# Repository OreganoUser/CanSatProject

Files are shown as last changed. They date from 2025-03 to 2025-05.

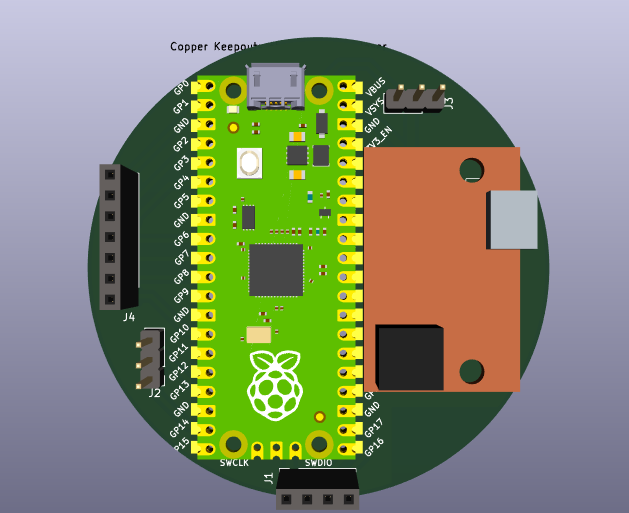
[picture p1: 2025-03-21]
PCB/model3d_1.png

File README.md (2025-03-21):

# Code Structure
## sensorsational_library
This folder contains all the functions. This folder **should be placed in the arduino libraries folder** to make it accessible to all other sketches.The functions are split up in different files depending on the component/function they belong to. The heart piece of the library is **general_definitions.h** since it contains all pin definitions, frequency definition, etc. **calibration_parameters.cpp** contains the calibration parameters for the LSM9DS1 which must be changed manually if a new calibration procedure is done.

## main
Main contains the code that is run on the can. It relies on external functions from the sensorsational_library and is kept small to keep it readable.

## calibration
calibration contains the calibration routines for the LSM9DS1 that have been taken from: https://github.com/FemmeVerbeek/Arduino_LSM9DS1/tree/master/examples. See also instructional video here: https://www.youtube.com/watch?v=BLvYFXoP33o. This calibration must be done in the real environment (inside the can with all components in place) **once** to determine the calibration parameters.

## magneto_calibration
magnet_calibration provides a better magnetic calibration than in the calibration folder. This sketch measure a large array of magnetic data and saves it as .txt file on the SD card. To get the calibration parameters, this .txt file must be loaded onto a computer and imported into the magneto v1.2 code (download here). The calibration parameters need to be input into the calibration_paramters.cpp file in the sensorsational_library.

## motor_test
motor_test is example code to set the BLDC motor speed for the propellers. To be done: implement functions that set motor speeds and can be called inside the main code and add them to the sensorsational_library.

## orientation
orientation contains example code on how to use the SensorFusion library to calculate the magnetic heading. To be done: implement functions that can be called inside the main code and add them to the sensorsational_library.

## receiver
receiver is example code for receiving the data (groundstation) from the radio module and outputting them to the serial.

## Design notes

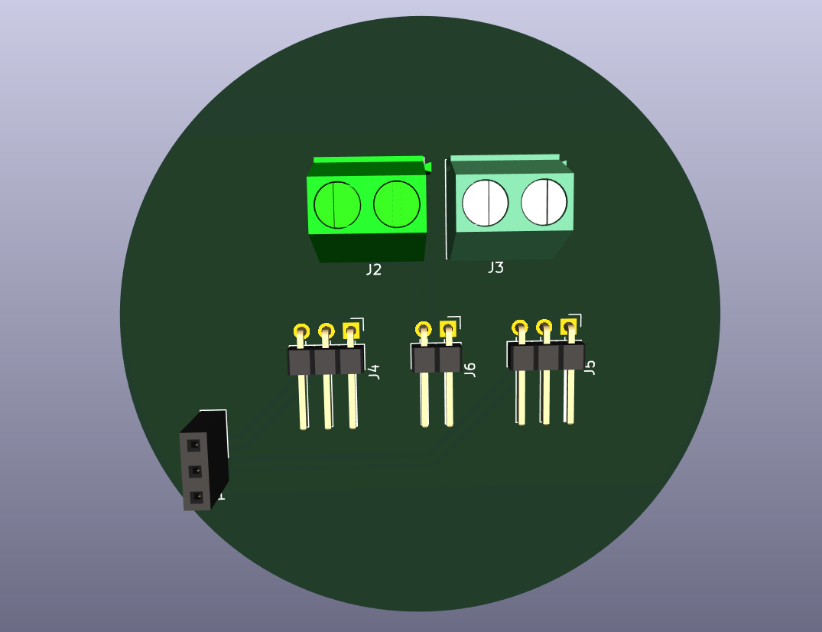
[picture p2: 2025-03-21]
PCB/model3d_0.png

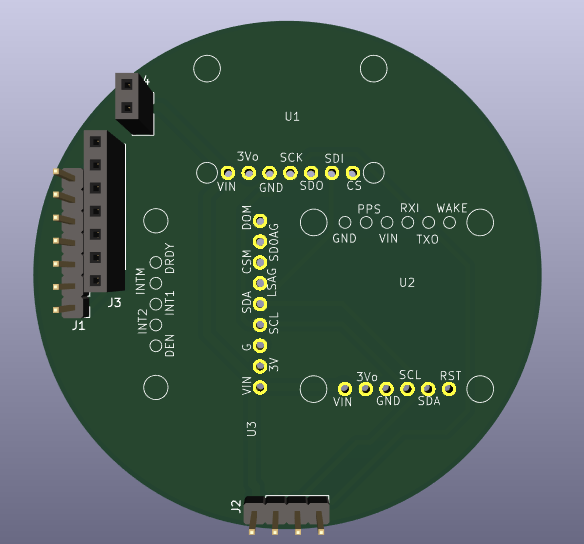
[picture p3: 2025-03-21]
PCB/model3d_2.png

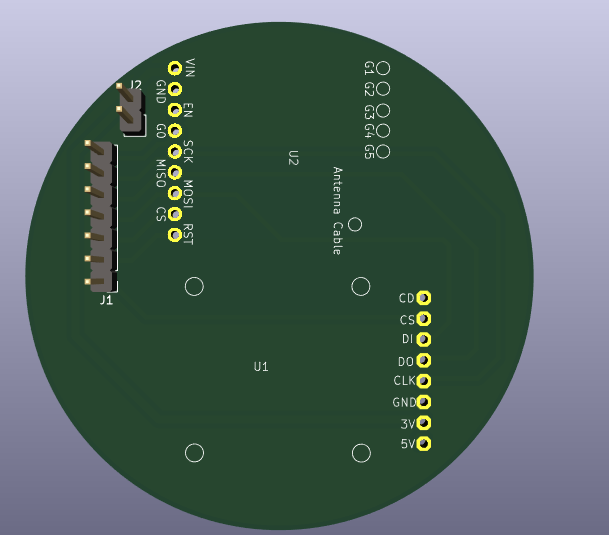
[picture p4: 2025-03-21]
PCB/model3d_3.png

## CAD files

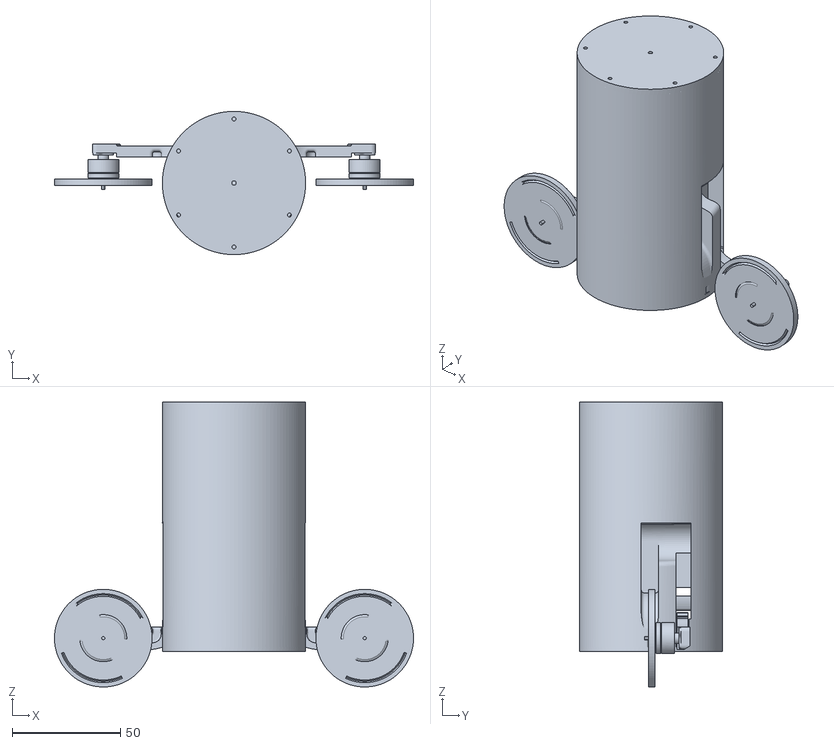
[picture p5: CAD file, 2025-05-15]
Evaluation/canSat prototyp 3 (platzoptimisation) v19.stl
165.5 x 66.0 x 131.3

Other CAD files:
Evaluation/animation.blend

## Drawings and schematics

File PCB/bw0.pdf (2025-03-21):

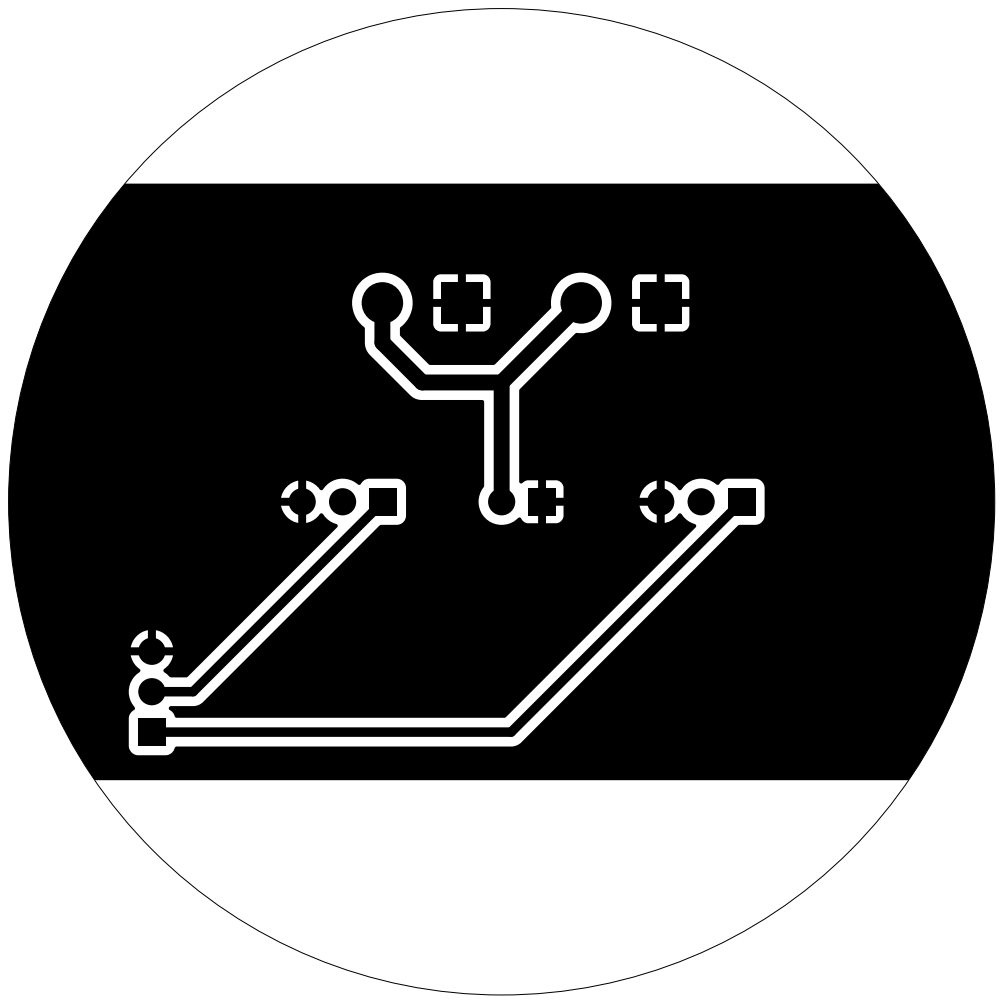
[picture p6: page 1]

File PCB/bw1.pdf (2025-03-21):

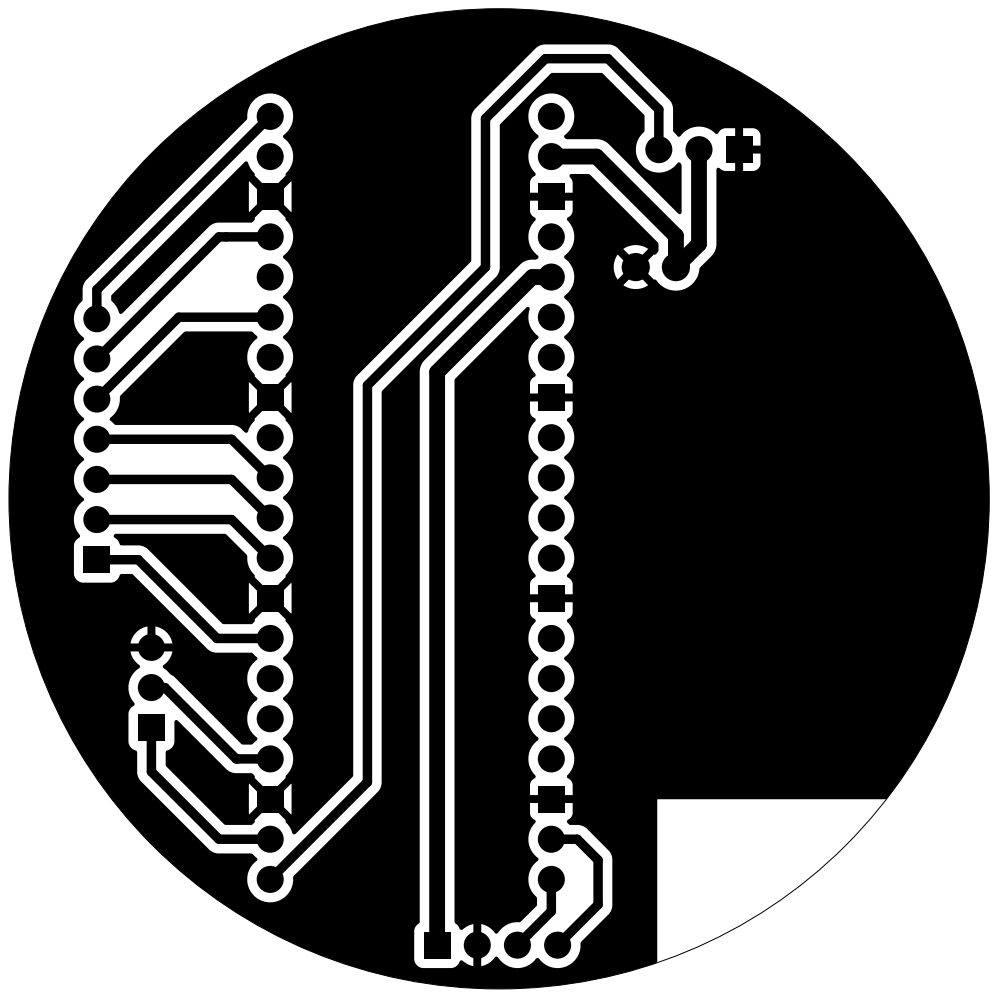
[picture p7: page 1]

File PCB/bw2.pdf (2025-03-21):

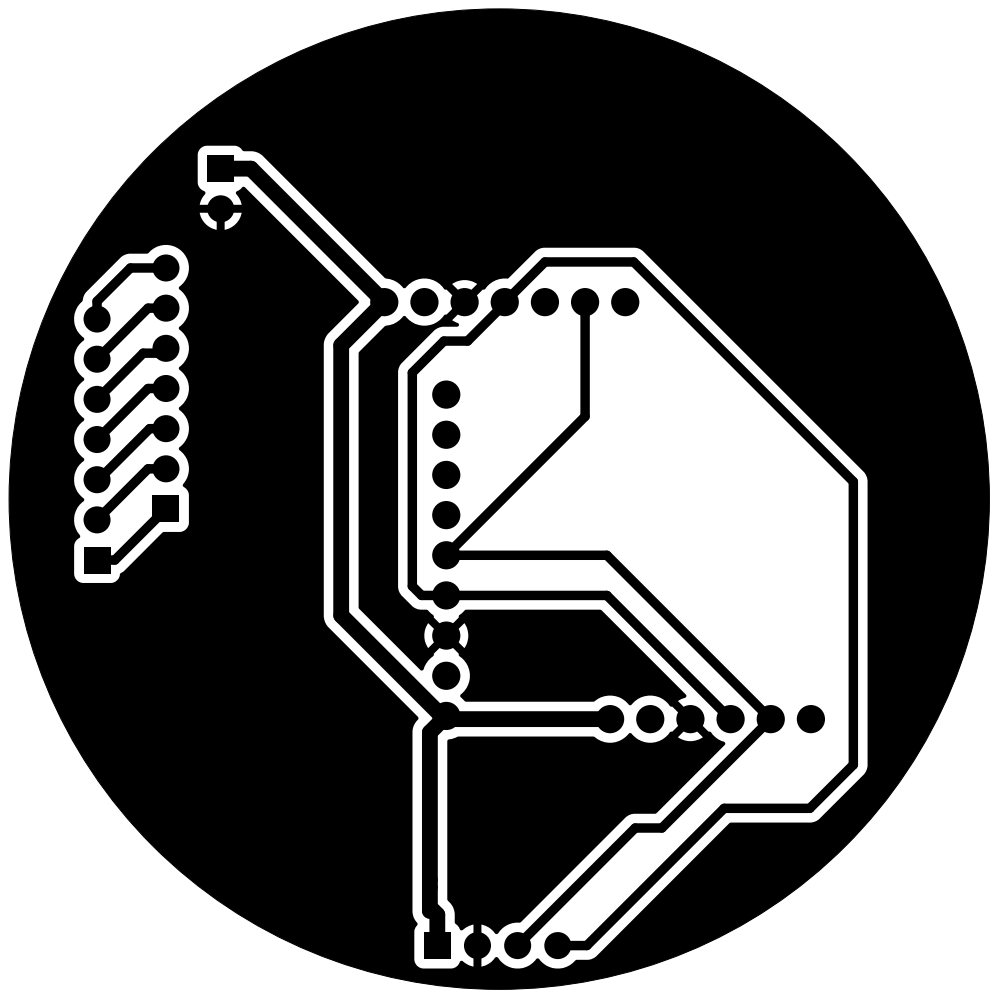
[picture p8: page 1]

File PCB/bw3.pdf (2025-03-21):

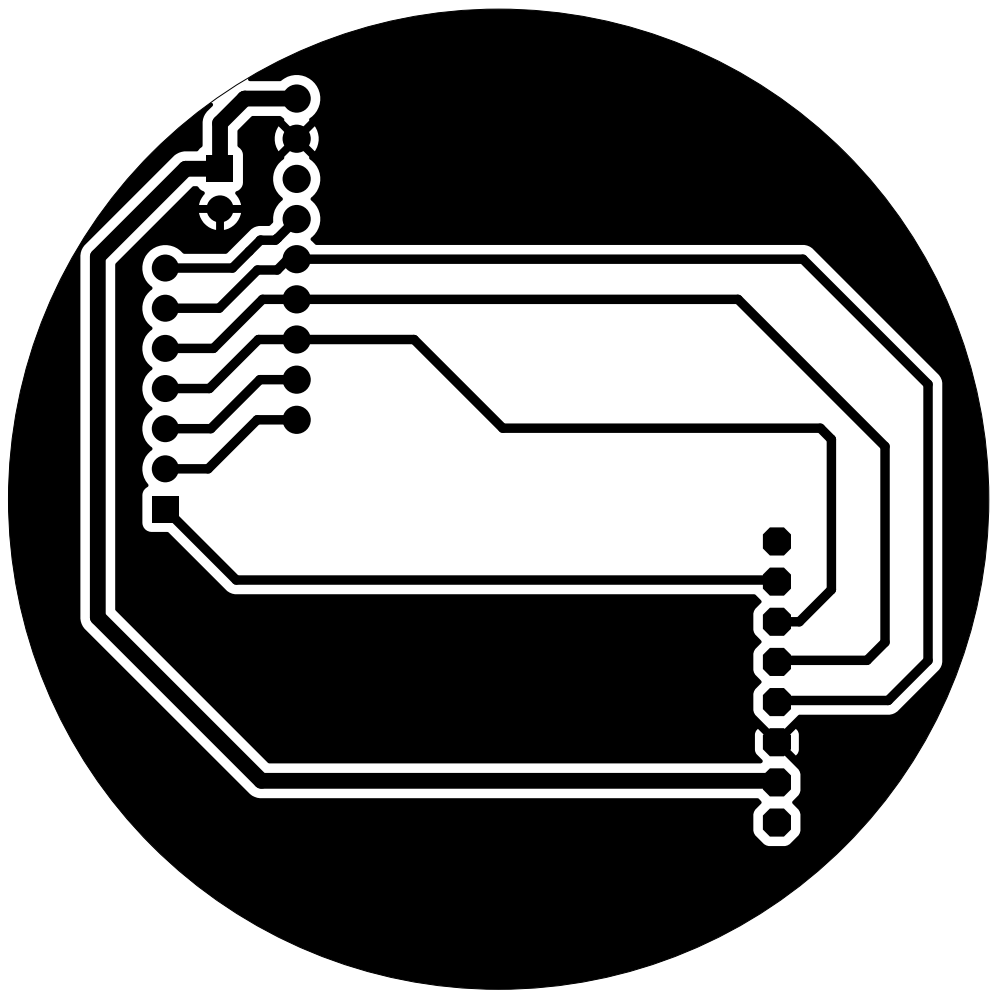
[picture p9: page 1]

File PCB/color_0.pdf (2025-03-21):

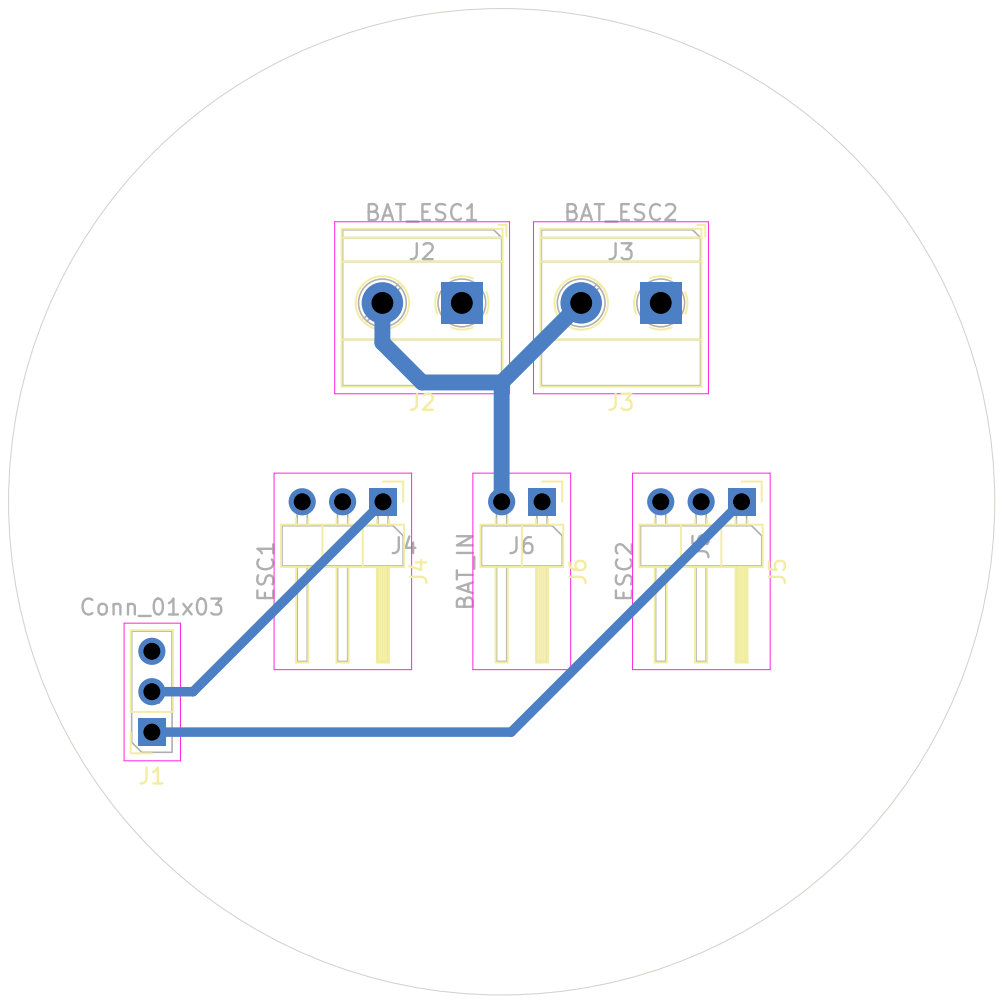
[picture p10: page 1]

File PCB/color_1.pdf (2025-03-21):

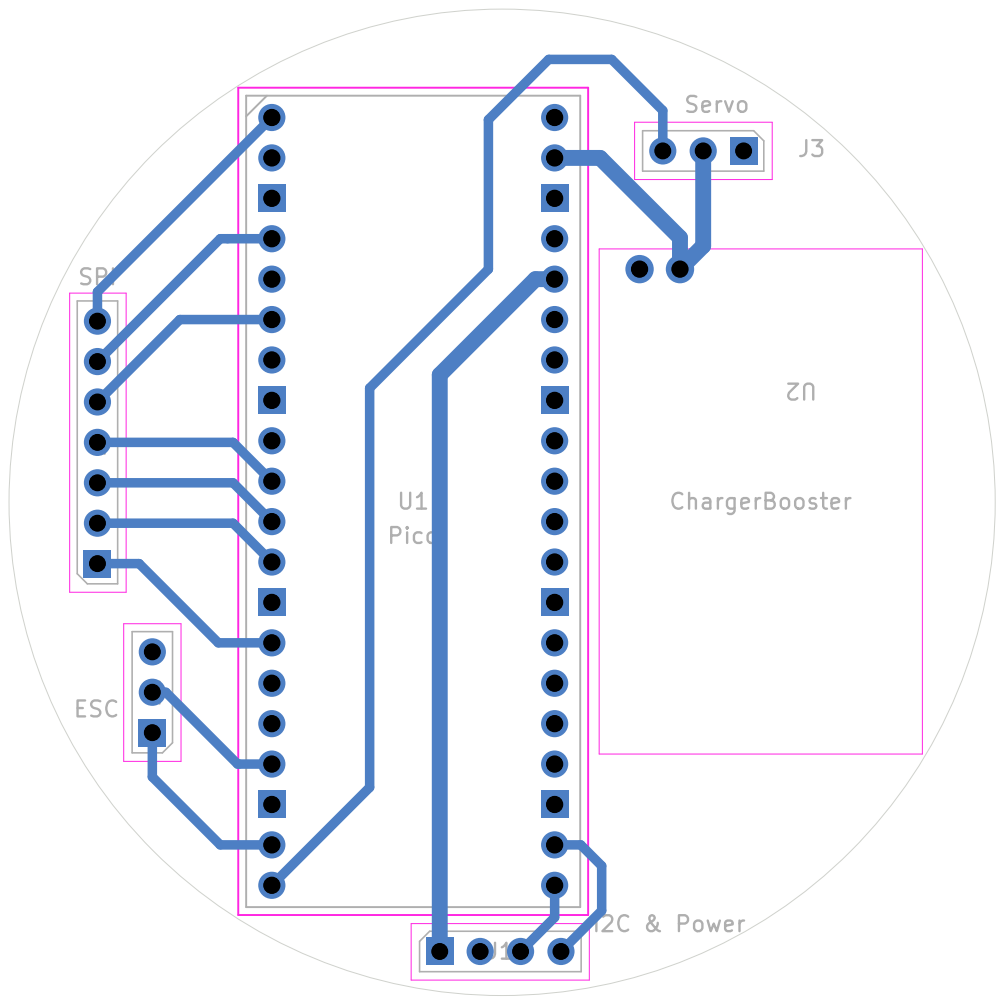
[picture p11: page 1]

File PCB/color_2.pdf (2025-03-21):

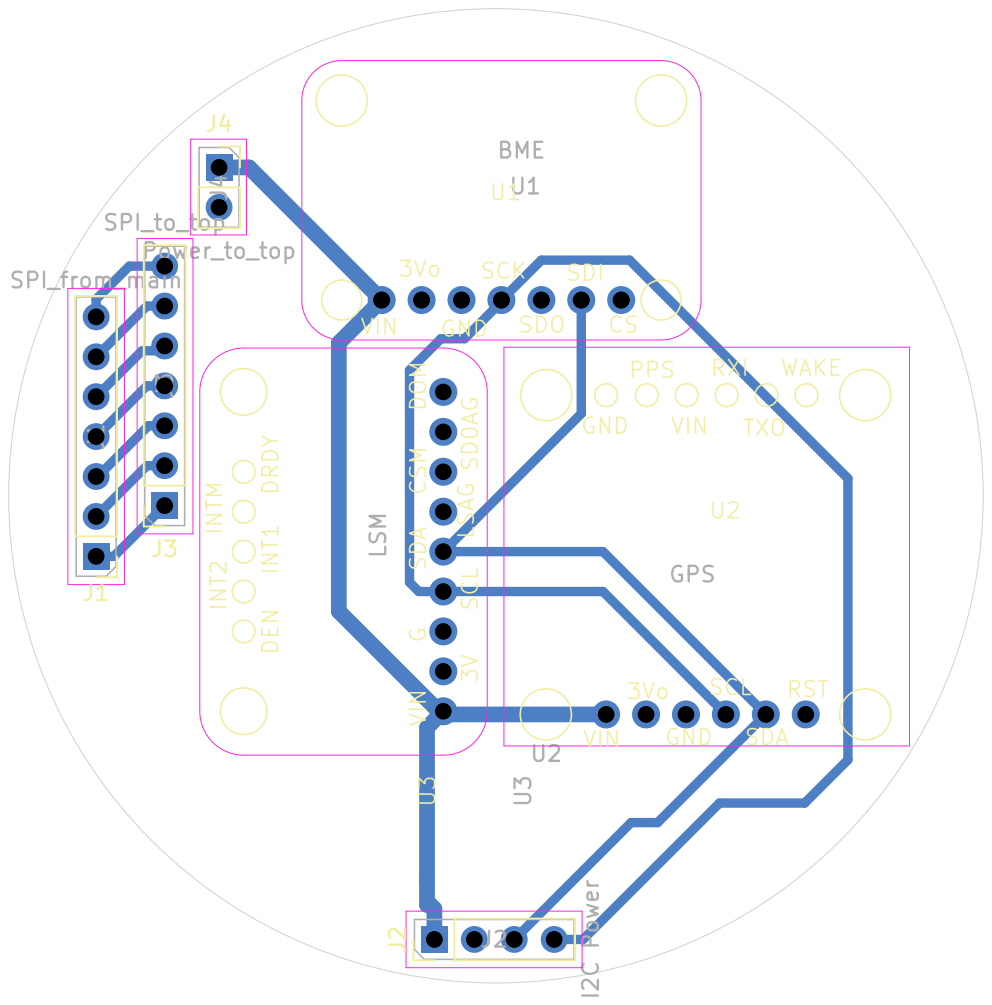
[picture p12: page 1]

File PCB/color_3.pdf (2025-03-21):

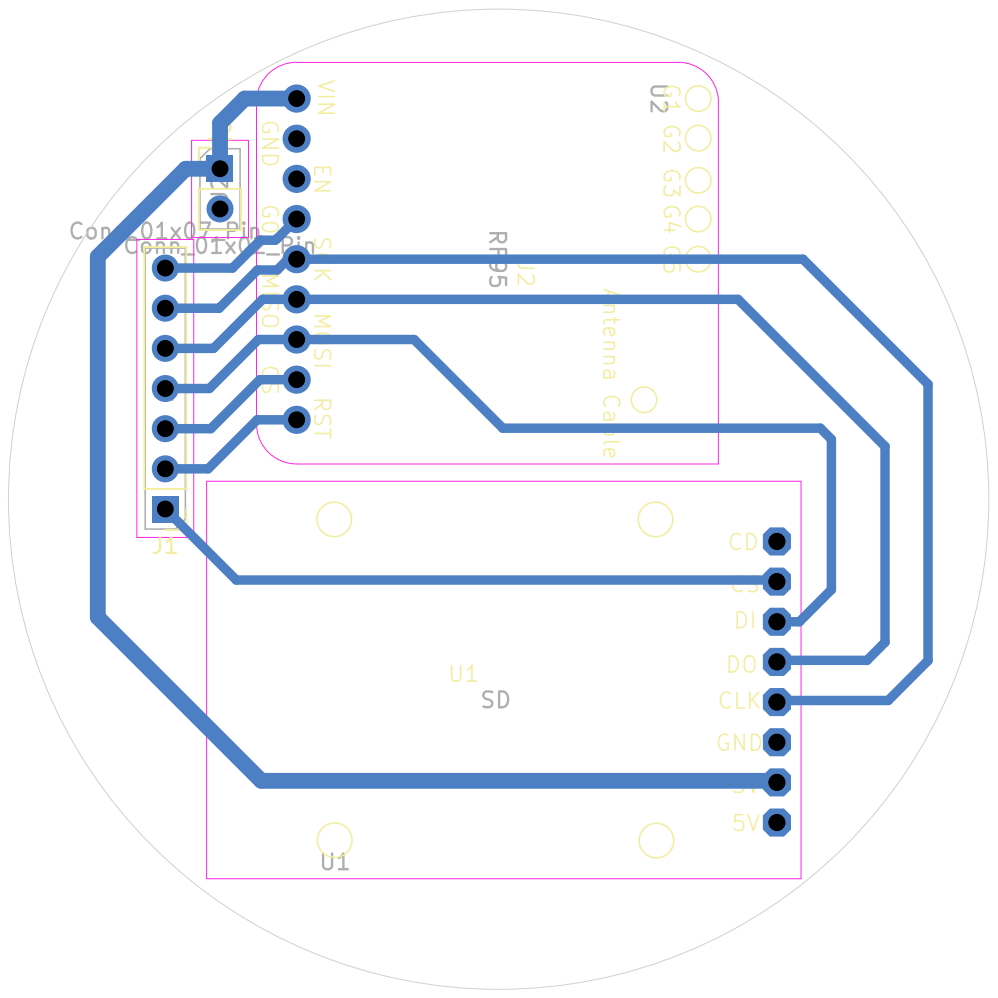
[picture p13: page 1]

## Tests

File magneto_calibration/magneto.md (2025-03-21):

The magneto program provides a better magnetic calibration than the simple model used in /calibration.

# Procedure
- Execute the the magneto_calibration.ino sketch and rotate the can around. Make sure to get all possible positions of the can!
- The data is measured during a certain duration (can be set in the sketch).
- After the measurement is done, take the created .txt file from the SD card and transfer it to the computer.
- Load the .txt file into the magneto program, set the magnetic field strength (taken from here: [Magnetic Field Strenght Calculator](https://www.ngdc.noaa.gov/geomag/calculators/magcalc.shtml#igrfwmm) ) and execute.
- Write the parameters into the calibration_parameters.cpp file (combined bias -> magBias and the 9 values are written to softIron in the following order: upper left, upper centre, upper right, second row left, ...).

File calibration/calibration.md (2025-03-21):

# Explanations for the calibration procedure
This procedure is taken from https://github.com/FemmeVerbeek/Arduino_LSM9DS1/tree/master/examples.
An instructional video that shows the procedure can be found here: https://www.youtube.com/watch?v=BLvYFXoP33o

## Setting up the code
- The sensorsational_library must be in the arduino/libraries folder.
- The SensorFusion (https://github.com/aster94/SensorFusion/tree/master/examples) library must be installed.
- Change Line 33 in the file: Arduino/libraries/Sensorfusion/src/Sensorfusion.cpp to #define betaDef     2.0f        	// 2 * proportional gain

## Executing the accelerometer calibration
- Set the can on a horizontal surface (use a water level!) and leave it. It is important that it isn't moving during calibration.
- Execute calibration.ino and select accelerometer.
- Follow the instructions and do the calibration for the 3 axes (axes are labelled on the LSM9DS1).

## Executing the gyro calibration
- Set the can on a flat horizontal surface.
- Execute calibration.ino and select gyro.
- Follow the instructions. The rotation angle can be set in the code (the bigger, the better in theory)
- Repeat for all 3 axes.

## Executing the magnetic calibration
- The magnetic field strength must be looked up (https://www.ngdc.noaa.gov/geomag/calculators/magcalc.shtml#igrfwmm) and put into the general_definitions.h file.
- **Make sure you are away from all magnetic disturbance (power outlets, speakers, ...)!** This is best done outside and in the real environment (with all components installed).
- Follow the instructions on the screen and rotate the can around all axes.
- Stop when the max and min values don't change much anymore.
- Note: the magneto_calibration is preferred because it's more accurate.

## Setting the calibration parameters
- Write the determined parameters into the calibration_parameters.cpp file.
- For the simple magnetic calibration, use magOffsets and magSlopes. If the magneto calibration is done, use magBias and softIron.

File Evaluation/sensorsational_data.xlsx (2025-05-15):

Data | Packet Number | Timestamp (s) | Temperature (°C) | Pressure (hPa) | Altitude (m) | Humidity (%) | GPS Fix | Latitude | Longitude | Altitude (m) | Speed (knots) | Angle (°) | ax (m/s2) | ay (m/s2) | az (m/s2) | gx (rad/s) | gy( rad/s) | gz (rad/s) | mx (microTesla) | my (microTesla) | mz (microTesla) | Yaw (°) | Roll (°) | Pitch (°) | Flight Stage | RSSI
Variable Type | int | Float, 1 decimal | Float, 1 decimal | Float, 1 decimal | Float, 1 decimal | int | int | Float, 5 decimals | Float, 5 decimals | Float, 1 decimal | Float, 3 decimals | int | Float, 4 decimals | Float, 4 decimals | Float, 4 decimals | Float, 4 decimals | Float, 4 decimals | Float, 4 decimals | Float, 4 decimals | Float, 4 decimals | Float, 4 decimals | int | int | int | int | int (negative value)
Explanation |  |  |  |  |  |  | Is actually of bool type. 0: GPS has no fix, 1: GPS has fix |  |  | This value can be different from the altitude that is determined from pressure sensor. | Speed over ground (horizontal speed). Needs to be converted to m/s! | This is the direction we are moving in. |  |  |  |  |  |  |  |  |  | Is basically the same as magnetic heading | Inclination of Cansat (leaning left or right) | Inclination of Cansat (looking up or down) | -1: value before things have been calculated 0: before launch 1: launch detected 2: reached a specific threshold height with rocket 3: Cansat fall detected 4: Cansat close to ground | Signal strength, the bigger the number (the less negative), the better ist the reception
What can we do with this data? |  |  | Graph as function of time | Display value on dashboard | Graph as function of time. Calculate vertical descent speed and display as function of time | Display value on dashboard | Display value on dashboard (red and green light?) | Display value on dashboard. Plot position on map. | Display value on dashboard. Plot position on map. |  | Graph as function of time. | Display value on dashboard. Could be drawn as arrow on map. |  |  |  |  |  |  |  |  |  |  |  |  | Display the flight stage on dashboard | Display the flight stage on dashboard

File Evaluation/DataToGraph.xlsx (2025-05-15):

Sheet: data
PackeNumber | Timestamp | Temperature | Pressure | Altitude (Pressure) | Humidity | GPSFix | Latitude | Longitude | Altitude (GPS) | Speed (Knots) | Angle | ax | ay | az | gx | gy | gz | mx | my | mz | Magheading | Yaw | Roll | Pitch | FlightStage
0 | 27.3 | 28.1 | 952.6 | 531.9 | 39 | 0 | 0 | 0 | 0 | 0 | 0 | 1.0324 | -0.0397 | 9.7728 | 0.0401 | 0.0395 | 0.029 | 10.3471 | 25.5243 | -34.4517 | 207 | 60 | -144 | -59 | 0
1 | 27.5 | 24.2 | 946.8 | 582.6 | 40 | 0 | 0 | 0 | 0 | 0 | 0 | 2.315 | -0.4971 | 9.4018 | 0.0237 | 0.0193 | -0.1156 | 9.3375 | 26.7741 | -35.3652 | 207 | 60 | -143 | -60 | 0
2 | 27.9 | 23.6 | 945.9 | 590.8 | 38 | 0 | 0 | 0 | 0 | 0 | 0 | 0.8691 | 0.0124 | 9.8925 | 0.0704 | 0.0819 | 0.0554 | 10.1578 | 27.1099 | -35.8639 | 208 | 62 | -144 | -59 | 1
3 | 28.3 | 23.9 | 946.3 | 587.3 | 39 | 0 | 0 | 0 | 0 | 0 | 0 | 1.9175 | -0.3217 | 9.6601 | 0.2768 | 0.447 | 0.0128 | 15.0503 | 25.9741 | -35.828 | 199 | 58 | -141 | -56 | 1
4 | 28.8 | 23.9 | 946.4 | 586.0 | 39 | 0 | 0 | 0 | 0 | 0 | 0 | 3.6876 | -1.3088 | 8.9558 | 0.3225 | 0.733 | -0.6253 | 20.9634 | 29.2886 | -31.226 | 236 | 85 | -161 | -52 | 1
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

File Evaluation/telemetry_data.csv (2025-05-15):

PacketNumber | Timestamp | Temperature | Pressure | AltitudePressure | Humidity | GPSFix | Latitude | Longitude | AltitudeGPS | SpeedKnots | Angle | ax | ay | az | gx | gy | gz | mx | my | mz | Magheading | yaw | roll | pitch | flightStage | RSSI
746 | 355.1 | 28.6 | 949.1 | 562.9 | 40 | 1 | 50.48238 | 6.18066 | 519.7 | 0.150 | 128 | 1.1081 | -0.1902 | -9.0444 | 0.3261 | 0.0219 | 0.0135 | -20.7581 | 16.0941 | 48.6924 | 226 | 52 | -165 | -0 | 1 | -78
747 | 355.6 | 28.8 | 949.4 | 560.2 | 40 | 1 | 50.48239 | 6.18066 | 519.7 | 0.050 | 128 | 1.2821 | 0.2139 | -7.6441 | 0.0204 | 0.0784 | 0.0216 | -18.7387 | 13.5363 | 48.5726 | 229 | 54 | -164 | -3 | 1 | -76
748 | 356.0 | 28.8 | 949.3 | 561.0 | 40 | 1 | 50.48239 | 6.18066 | 519.7 | 0.050 | 128 | 1.5992 | 0.4710 | -9.4588 | -0.1141 | 0.1788 | 0.1467 | -20.2800 | 16.0953 | 47.7807 | 224 | 53 | -168 | -0 | 1 | -77
749 | 356.5 | 29.0 | 949.6 | 558.5 | 41 | 1 | 50.48238 | 6.18066 | 519.7 | 0.050 | 128 | 0.5721 | -0.9474 | -9.1148 | 0.6243 | -0.3661 | 0.3955 | -20.8277 | 20.2464 | 47.3683 | 227 | 51 | -169 | 1 | 1 | -83
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

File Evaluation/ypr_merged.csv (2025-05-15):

time_s | yaw_deg | pitch_deg | roll_deg
2502 | 276 | -20 | -3
2502 | 275 | -15 | 0
2503 | 280 | -12 | -2
2503 | 275 | -10 | -2
2504 | 272 | -9 | -4
2504 | 267 | -9 | 2
2505 | 263 | -10 | -1
2505 | 255 | -11 | 3
2505 | 252 | -11 | 4
2506 | 247 | -12 | 6
2506 | 241 | -12 | 8
2507 | 236 | -13 | 8
2507 | 227 | -13 | 12
2508 | 221 | -15 | 15
2508 | 215 | -13 | 15
2509 | 208 | -15 | 17
2509 | 201 | -12 | 23
2510 | 194 | -10 | 24
2510 | 189 | -9 | 29
2510 | 182 | -8 | 36
2511 | 176 | -7 | 39
2511 | 171 | -5 | 43
2512 | 165 | 1 | 48
2512 | 160 | 6 | 50
2513 | 155 | 16 | 52
2513 | 151 | 23 | 56
2514 | 149 | 29 | 58
2514 | 147 | 38 | 60
2515 | 147 | 47 | 63
2515 | 145 | 57 | 62
2515 | 148 | 66 | 64
2516 | 151 | 75 | 68
2516 | 167 | 81 | 83
2517 | 234 | 85 | 149
2517 | 48 | 47 | -61
2518 | 255 | 29 | -61
2518 | 220 | 7 | 56
2519 | 71 | -51 | 60
2519 | 32 | 51 | -44
2520 | 277 | 40 | 7
2520 | 317 | -44 | -153
2521 | 171 | 11 | 29
2521 | 135 | -29 | -96
2521 | 270 | -26 | 157
2522 | 16 | 45 | -159
2522 | 114 | 13 | 144
2523 | 240 | 32 | -107
2523 | 298 | -24 | 151
2524 | 53 | 62 | -146
2524 | 160 | 13 | 176
2525 | 274 | 15 | 142
2525 | 90 | 53 | -125
2526 | 193 | 3 | -179
2526 | 277 | 58 | 103
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

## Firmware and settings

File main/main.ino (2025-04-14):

#include "general_definitions.h"
#include "bme_functions.h"
#include "gps_functions.h"
#include "lsm9ds1_functions.h"
#include "sd_functions.h"
#include "rf69_functions.h"
#include "rf95_functions.h"
#include "orientation.h"
#include "direction_control.h"
#include "flight_stages.h"



// define array for saving timestamp
float time_array[1] = {0.0};
int time_precisions[1] = {1};

// Create one structure that contains all variable arrays
// Arrays for sensor variables are already defined in the respective function files
int number_of_arrays = 6;
float* data_arrays[] = {time_array, bme_data, gps_data, calibrated_lsm_data, orientation_data, flight_stage_data};
size_t data_array_sizes[] = {1, 4, 6, 9, 4, 1};
// This array holds the digits precision needed for each of the sensor variables
int* precisions[] = {time_precisions, bme_precisions, gps_precisions, lsm_precisions, orientation_precisions, flight_stage_precisions};

// Create buffer for data string
char data_string[MESSAGE_BUFFER_SIZE] = {0};

// counts how many times loop is executed
int iteration_counter = 0;


void setup() {
  // Set I2C pins
  Wire.setSDA(I2C_SDA);
  Wire.setSCL(I2C_SCL);
  Wire.setClock(400000);
  Wire.begin();

  // Set SPI PINS
  SPI.setRX(SPI_RX);
  SPI.setTX(SPI_TX);
  SPI.setSCK(SPI_SCK);

  // Start Serial and wait until it opens
  Serial.begin(115200);
  while (!Serial)
    delay(200);

  setup_bme(bme);
  setup_gps(gps);
  setup_lsm9ds1(lsm);
  setup_sd_card();
  
  // For the RF95 module to work:
  // Need to call setup_sd_card() even if no SD card is connected!
  // Else: SPI has problems and it won't work
  setup_rf95(rf95);

  initMotors(); //esc's
    escLeft.writeMicroseconds(0);
    escRight.writeMicroseconds(0);
    arms_deployed = false;

  //Servo
  //servo.attach(SERVO_PIN);
  delay(1000);
  // start time measurement (in seconds)
  time_array[0] = millis() / 1000.0;
}


void loop() {
  // Estimate heading using LSM9DS1
  // This should be done as a first step because direction control needs accurate values
  // and we need to send it back to ground station, so it needs to happen before sending!
  // the number in update_mag_heading should be about 100 (200 should also work)
  // less than that gives bad accuracy
  // much more (for example 1000) slows execution down by quite a bit
  update_mag_heading(100);
  // Execute sensor data collection and writing functions
  get_bme_data(bme_data);
  get_gps_data(gps_data);
  get_calibrated_lsm9ds1_data(lsm, calibrated_lsm_data, bias_corrected_magnetic);
  //update timestamp (in s)
  time_array[0] = millis() / 1000.0;
  create_data_string(data_string, iteration_counter, data_arrays, data_array_sizes, number_of_arrays, precisions);
  // need to do create_data_string before write_data_to_file!!!
  write_data_to_file(logfile_name, data_string);
  send_data_rf95(rf95, data_string);
  iteration_counter++;

  // automatic
  calc_flight_stage();
  //manual
  //manual_flight_stage_override();
  
  // calculate flight stage here and do actions (deploy arms, adjust direction etc) (not working well now)

  Serial.println(orientation_data[0]);
  adjustDirection();
}

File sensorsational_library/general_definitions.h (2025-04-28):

//I2C pins (BME280, GPS, LSM9DS1)
//Attention to I2C Bus! If using I2C0 bus, we need to use Wire
//if using I2C1 bus (check pico pinout), we need to use Wire1 and change accordingly in setup functions
#define I2C_SDA  16
#define I2C_SCL  17

//Shared SPI pins (radio and SD)
#define SPI_RX 4
#define SPI_TX 7
#define SPI_SCK 2

// RF95
#define RF95_CS 8
#define RF95_RST 9
#define RF95_G0 0
#define RF95_FREQ 433.4
#define MESSAGE_BUFFER_SIZE 275
// Define the CanSat's and the ground station's address
#define CANSAT_ADDRESS 42
#define GND_STATION_ADDRESS 211

// RF69
//can use same CS, RST and G0 pins as RF95 since they are not used together!
#define RF69_CS 8
#define RF69_RST 9
#define RF69_G0 0
#define RF69_FREQ 433.4
#define MAX_MESSAGE_SIZE_RF69 61 //max total message length
#define HEADER_SIZE_RF69 10 //space reserved for the header (iteration_counter, chunk number)
#define MAX_DATA_SIZE_RF69 (MAX_MESSAGE_SIZE_RF69 - HEADER_SIZE_RF69)  // remaining space for actual data
#define MAX_CONCATENATED_STRING_LENGTH 255 // length of string for all sensor data. 255 bytes should be enough but can be changed

// SD card
#define SD_CS 10

// Servo
#define SERVO_PIN 15

// Motors
#define MOTOR1_PIN 14
#define MOTOR2_PIN 13

#define SEA_LEVEL_PRESSURE 1023 // needs to be changed the day of launch so that bme calculates correct altitude

// for calibration
#define gravity 9.809  // Gravity constant
#define mag_intensity 48.765 // intensity of magnetic field (in microtesla) at your location have to research this! https://www.ngdc.noaa.gov/geomag/calculators/magcalc.shtml#igrfwmm

// define which calibration to use when getting lsm data.
// SIMPLE_CAL is simple offset slope model
// FULL_CAL is Hard and soft iron model
//#define SIMPLE_CAL
#define FULL_CAL

// define target coordinates (Paris for now)
#define TARGET_LAT 48.8575
#define TARGET_LON 2.3514


// define threshold and meters_delay to determine flight stage
// threshold contains the altitude at which we can say that the cansat has actually been lifted by the rocket
#define LAUNCH_THRESHOLD 20 // m
#define ALTITUDE_THRESHOLD 80
#define DROP_THRESHOLD 20
#define LAUNCH_ACCELERATION 16 //m/s²
#define FALL_ACCELERATION 3 // m/s²
#define FALL_DELAY 3000 //ms
#define IMPACT_ACCELERATION 20 // m/s²

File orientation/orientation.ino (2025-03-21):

#include <general_definitions.h>
#include <lsm9ds1_functions.h>
#include <SensorFusion.h>

SF fusion;

float pitch, roll, yaw, magheading, Xh, Yh;
float deltat;


void setup()
{
	// Set I2C pins
	Wire.setSDA(I2C_SDA);
	Wire.setSCL(I2C_SCL);
	Wire.setClock(400000);
	Wire.begin();

	// Start Serial and wait until it opens
	Serial.begin(115200);
	while (!Serial)
		delay(200);

	setup_lsm9ds1(lsm);
}


void loop()
{
  deltat = fusion.deltatUpdate();
  get_calibrated_lsm9ds1_data(lsm, calibrated_lsm_data, bias_corrected_magnetic);
  // invert y axis to get right-handed coordinate system.
  fusion.MadgwickUpdate(calibrated_lsm_data[3], -calibrated_lsm_data[4], calibrated_lsm_data[5], calibrated_lsm_data[0] ,-calibrated_lsm_data[1], calibrated_lsm_data[2], calibrated_lsm_data[6], -calibrated_lsm_data[7], calibrated_lsm_data[8], deltat);

  pitch = fusion.getPitch();
  roll = fusion.getRoll();
  yaw = fusion.getYaw();

  // calculating magnetic heading (much stabler than yaw calculation)
  // from https://avionicsduino.com/index.php/en/digital-compass/
  Xh = calibrated_lsm_data[6] * cos(pitch / 180 * PI) - calibrated_lsm_data[8] * sin(pitch / 180 * PI);
  Yh = -calibrated_lsm_data[6] * sin(roll / 180 * PI) * sin(pitch / 180 * PI) - calibrated_lsm_data[7] * cos(roll / 180 * PI) + calibrated_lsm_data[6] * sin(roll / 180 * PI) * cos(pitch / 180 * PI);
  magheading = 180 - atan2(Yh, Xh) * 180 / PI;
  if (magheading < 0)
    magheading += 360;


  Serial.print("Pitch: ");
  Serial.print(pitch);
  Serial.print("\tRoll: ");
  Serial.print(roll);
  Serial.print("\tYaw: ");
  Serial.print(yaw);
  Serial.print("\tMagheading: ");
  Serial.print(magheading); 
  Serial.print("\r"); // Carriage return to overwrite the same line
}

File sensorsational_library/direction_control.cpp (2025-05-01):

#include "direction_control.h"
#include "flight_stages.h"
#include "math.h"
#include "Servo.h"
#include "Arduino.h"
#include "gps_functions.h" // needed to access current pos
#include "orientation.h" // needed to access current heading
#include "general_definitions.h" // needed to access target pos

extern bool arms_deployed;
Servo servo_arms;

Servo escLeft;
Servo escRight;


void initMotors() {
  servo_arms.attach(SERVO_PIN);
  servo_arms.write(200);
  escLeft.attach(MOTOR1_PIN);
  escRight.attach(MOTOR2_PIN);
}

void adjustDirection()
{

  if(flight_stage == 3){
    Serial.println("Deploying Arms");
    servo_arms.write(10);
    arms_deployed = true;
  } else {
    servo_arms.write(190);
    arms_deployed = false;
    escLeft.writeMicroseconds(0);
    escRight.writeMicroseconds(0);
  }

  if(arms_deployed && flight_stage == 3){

  // this function gets current position from gps and current magnetic heading from orientation
  // and calculates the needed adjustment to head towards target coordinates
  // the target coordinates are defined in general_definitions.h as TARGET_LAT and TARGET_LON
  float currentLat = gps_data[1];
  float currentLon = gps_data[2];
  float currentHeading = orientation_data[0]; //magheading

  float phi1 = currentLat * PI / 180.0;
  float phi2 = TARGET_LAT * PI / 180.0;
  float dLon = (TARGET_LON - currentLon) * PI / 180.0;

  // Variablen für atan2
  float y = sin(dLon) * cos(phi2);
  float x = cos(phi1) * sin(phi2) - sin(phi1) * cos(phi2) * cos(dLon);

  // Zielwinkel
  float targetHeading = atan2(y, x) * 180.0 / PI;
  targetHeading = fmod(targetHeading + 360, 360);

  // Winkelabweichung
  float delta = fmod(targetHeading - currentHeading + 360, 360);

  Serial.println(delta);

  if (delta < TOLERANCE || delta > 360 - TOLERANCE) {
    moveForward();
  } else if (delta > 180) {
    turnLeft(delta);
  } else {
    turnRight(delta);
  }
}
}

void turnLeft(float delta) {
  Serial.println("Turning Left");
  int speedAdjustment = constrain(-(delta-360), 0, 100);
  Serial.print("adj");
  Serial.println(speedAdjustment);
  escLeft.writeMicroseconds(2000 - speedAdjustment*0.2);
  escRight.writeMicroseconds(2000);
}
 
void turnRight(float delta) {
  Serial.println("Turning Right");
  int speedAdjustment = constrain(delta, 0, 100);
  Serial.print("adj");
  Serial.println(speedAdjustment);
  escLeft.writeMicroseconds(2000);
  escRight.writeMicroseconds(2000 - speedAdjustment*0.2);
}
 
void moveForward() {
    Serial.println("Vollgas!");
    escLeft.writeMicroseconds(2000);
    escRight.writeMicroseconds(2000);
}

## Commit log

2025-03-21 Added the custom library files
    These library files should be placed in the arduino libraries folder so that all the sketches can access them.
2025-03-21 Groundstation receiver code first commit
    This is the code that runs on the groundstation. Receives the data and passes it on to serial to be processed by the interface code.
2025-03-21 Main code to run inside the can. Initial commit.
    This is the basic code that runs inside the can. For now it only reads, writes and sends data. Needs to be updated to get orientation, position, calculate trajectory and update motor settings.
2025-03-21 Initial commit.
    BLDC motor testing.
2025-03-21 Initial Commit.
    This is example code on how to get magnetic direction from the LSM9DS1 data using the SensorFusion library. Also uses a calculation method from https://avionicsduino.com/index.php/en/digital-compass/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
2025-03-21 Initial commit
    This is code to do a simple linear calibration of the LSM9DS1 module. Code from: https://github.com/FemmeVerbeek/Arduino_LSM9DS1/blob/master/examples/DIY_Calibration_Accelerometer/DIY_Calibration_Acc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
    See instruction video: https://www.youtube.com/watch?v=BLvYFXoP33o
2025-03-21 Added magneto12.exe
2025-03-28 expand for magnetic heading calculation
    all files have been modified to be able to calculate magnetic heading in main file. Necessary functions are in orientation.cpp/.h
2025-03-28 updated for orientation calculation
    The main file now supports calculation of orientation using sensorfusion
2025-03-30 added orientation and flight stage data to data string
2025-03-30 updated orientation and flight stages
    Change allows the orientation and flight stage data to be transformed into string easily with the existing create_data_string function
2025-04-24 flipped coordinate system so motors push forward
2025-04-27 adjust sampling for pressure
2025-04-27 turn iir filter off
2025-04-27 changed flight stages to bme data
2025-04-28 update flight stages to bme
    This is the code that was tested during drone drop testing
